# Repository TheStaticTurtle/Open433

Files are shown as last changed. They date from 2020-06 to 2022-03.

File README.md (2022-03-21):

# Open433

This project is an opensource usb 433Mhz rf transmitter / receiver based on an atmega328p the board uses a serial communication with a "packet" based systems (simples structs that are sent over the serial port).
The project has a basic but working implementation of a custom component for homeassistant  which is similar to the rpi_rf configuration)

See my blog articles on the implementation / creation of the project:

[https://blog.thestaticturtle.fr/open433-lets-turn-light-on-with-the-computer](https://blog.thestaticturtle.fr/open433-lets-turn-light-on-with-the-computer)

[https://blog.thestaticturtle.fr/creating-a-custom-component-for-homeassistant](https://blog.thestaticturtle.fr/creating-a-custom-component-for-homeassistant)

# Building the project

If you just got your own barebone pcbs you just need to flash the arduino bootloader to do that you can use any iscp programmer (or even "arduino as isp") for the bootloader I use the arduino uno bootloader the hardware is using an atmega328p running at 16MHz at 5V.
After that you just have to compile compile and upload the scketch in the arduino folder

# Using the project

## Using the library

If you don't use homeassistant you can see an example in the software folder.

## From homeassistant
If you want to use the board with homeassistant you need to create a `custom_components` folder in the homeassistant configuration directory (same one as the configuration.yaml) then you need to rename the `homeassistant_open433` to `open433` and put it in the `custom_components`.
Then after restarting the server you need to set the configure homeassistant to use the module:
```
open433:
  port: COM3
  speed: 9600 #(Optional default to 9600)
```
Then you can add switches like this:
```
switch:
  - platform: open433
    switches:
      KitchenLamp:
        code_on: 2523794944
        code_off: 2658012672
        protocol: 2 #(Optional default to 2)
        length: 32 #(Optional default to 32)
        signal_repetitions: 5 #(Optional default to 15)
        enable_receive: true #(Optional default to false) enable listening to incoming rf message of the switch codes
```
Or add binary sensors (with a possible timeout) like this:
```
binary_sensor:
  - platform: open433
    switches:
      inputA:
        code_on: 2389577216
        code_off: 2171473408
        protocol: 2 #(Optional default to 2)
        length: 32 #(Optional default to 32)
        on_timeout: 2 #(Optional 0 to turn off) Will turn off 2sec after receiving code_on, code_off will still be functional
```

An implementation of the light component has been done and can be used like this:
```
light:
  - platform: open433
    switches:
      BedSideLamp:
        levels:
          - brightness: 0
            code: 2658045484
          - brightness: 100
            code: 2523827756
        protocol: 2
        length: 32
        signal_repetitions: 5
        enable_receive: true
        force_levels: true
```
For this example, the entity KitchenLamp will send the code `2658045484` from brightness 0 to 99 and `2523827756` to 100 
The `force_levels` option allows the module to clamp homeassistant brightness slider to the specific value set in the config (ie. here sending the value 42 will go back to 0)
You can add multiple brightness stages with different codes, example:
```
- brightness: 0
  code: 2658045484
- brightness: 50
  code: 2926480940
- brightness: 100
  code: 2523827756
```
This will send the code `2658045484` from 0 to 49 , the code `2926480940` from 50 to 99 and the code `2523827756` at 100

You can also listen to events (open433_rx) to get received codes and send events to open433_tx with the following data to send an rf code:
```
code: 2658012672
protocol: 2
bitlength: 32
```

## Licences
- Software License: GPL v. 3
- Hardware License: CERN OHL v. 1.2
- Documentation License: CC BY-SA 4.0 International

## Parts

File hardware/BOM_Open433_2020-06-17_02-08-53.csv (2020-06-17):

ID | Name | Designator | Footprint | Quantity | Manufacturer Part | Manufacturer | Supplier | Supplier Part | LCSC Assembly
1 | HDR-M-2.54_2x2 | EXT | HDR-M-2.54_2X2 | 1 |  |  | LCSC | C66690
2 | 100nF | C4 | C1206 | 1 | FM31X104K251EEG | Prosperity Dielectrics | LCSC | C365814
3 | Antenna | U4,U6 | PCBANTENNA | 2 | ANT
4 | U217-04XN-XXR84 | USB1 | USB-A-SMD_U217-041N-4BV81 | 1 | U217-04XN-XXR84 | XKB Enterprise | LCSC | C319178
5 | 100nF | C3 | C1206 | 1 | GRM31C5C1H104JA01L | MuRata | LCSC | C97946
6 | DL-RXC2016BH-433M | U2 | WIRELM-TH_DL-RXC2016BH-433M | 1 | DL-RXC2016BH-433M | DreamLNK | LCSC | C381154
7 | 10K | R1,R4 | R1206 | 2 | CR-06JL7---10K | Viking Tech | LCSC | C280032
8 | 19-217/GHC-YR1S2/3T | LED2 | LED0603-R-RD | 1 | 19-217/GHC-YR1S2/3T | EVERLIGHT | LCSC | C72043 | Yes
9 | H34C-433MHZ | U1 | WIRELM-TH_H34C-433MHZ | 1 | H34C-433MHZ | Shenzhen LCHSTAR Elec | LCSC | C131030
10 | 19-223/Y2R6C-A01/2T | LED1 | LED-ARRAY-SMD_4P-L1.6-W1.5-TR-RD | 1 | 19-223/Y2R6C-A01/2T | Everlight Elec | LCSC | C282134
11 | TS665CJ | RST | SW-TH_4P-L6.0-W6.0-P4.50-LS6.5 | 1 | TS665CJ | SHOU HAN | LCSC | C393938
12 | Header-Female-2.54_2x3 | ISCP | HDR-3X2/2.54 | 1 | DS1023-2*3SF11 | CONNFLY | LCSC | C92272
13 | CH340G | U3 | SOIC-16_L9.9-W3.9-P1.27-LS6.0-BL | 1 | CH340G | WCH | LCSC | C14267 | Yes
14 | 12MHz | X1 | HC-49S_L11.4-W4.8 | 1 | C12000J517 | ZheJiang East Crystal Elec | LCSC | C279578
15 | 16MHz | X2 | HC-49S_L11.4-W4.8 | 1 | 49MD-16.000-20-20-20/A | Suzhou Liming Elec | LCSC | C240963
16 | 2.2K | R5,R6 | R0603 | 2 | QR0603F2K2P05 | Ever Ohms Tech | LCSC | C176136
17 | ATMEGA328P-AU | U5 | TQFP-32_L7.0-W7.0-P0.80-LS9.0-BL | 1 | ATMEGA328P-AU | MICROCHIP | LCSC | C14877 | Yes
18 | 22pF | C2,C1,C5,C6 | C1206 | 4 | 1206CG220J500NT | FH | LCSC | C1896

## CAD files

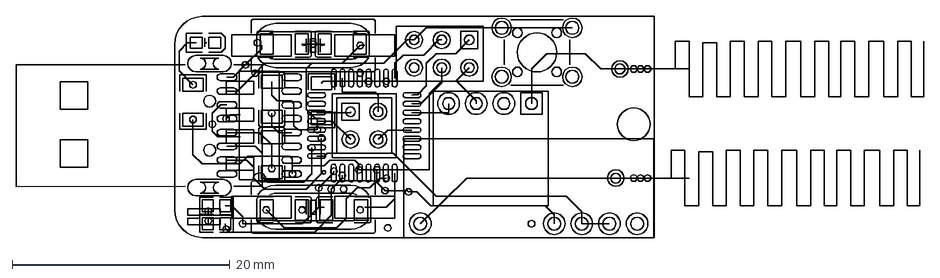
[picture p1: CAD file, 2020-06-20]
hardware/PCB_V2_2020-06-20_13-22-12.dxf
83.4 x 20.3 mm

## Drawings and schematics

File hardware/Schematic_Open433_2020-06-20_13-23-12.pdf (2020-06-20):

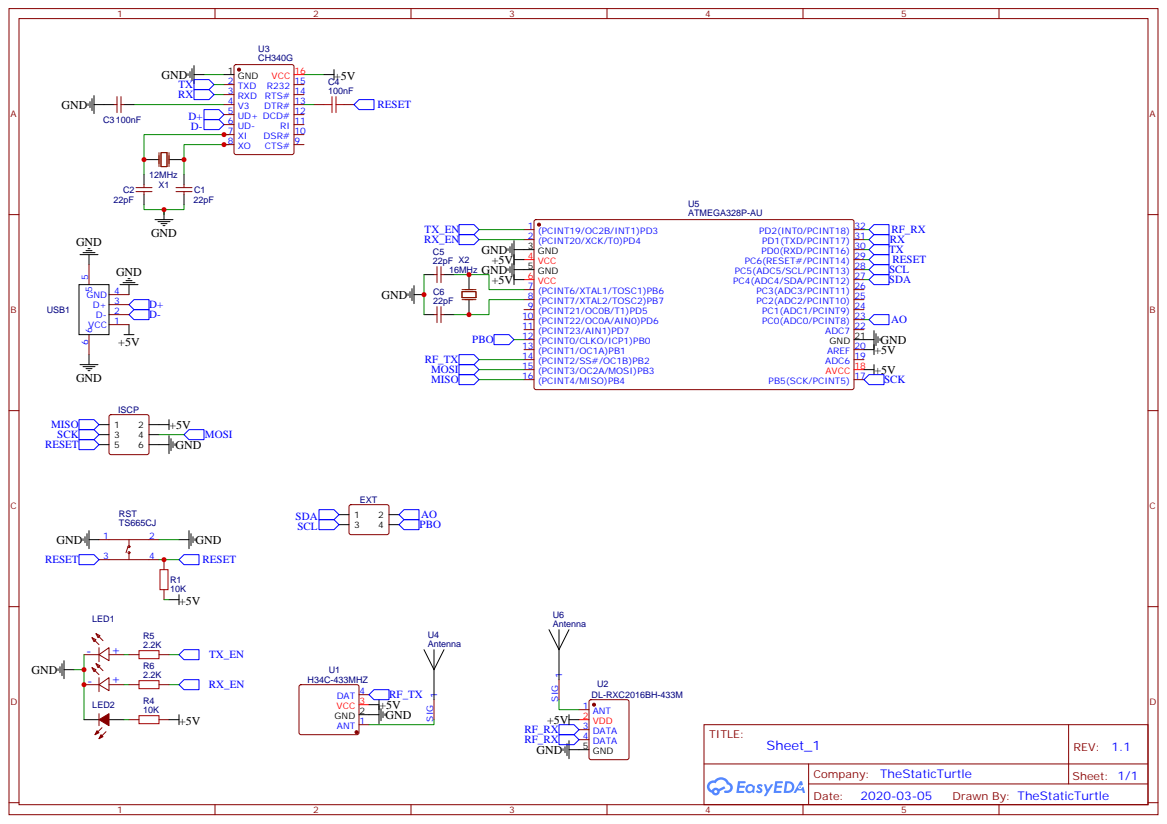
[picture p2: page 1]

DSR# 10 RI 11 DCD# 12 DTR# 13 RTS# 14 R232 15 VCC 16

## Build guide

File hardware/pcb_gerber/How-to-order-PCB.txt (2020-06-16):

How to Order PCB

Please refer to:
https://docs.easyeda.com/en/PCB/Order-PCB

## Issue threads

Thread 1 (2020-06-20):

HW source

pilotak, 2020-06-20:
Hi,
first of all nice project, i wanted to do the same. Would you be willing to share a source of PCB? only gerber appears to be uploaded. I can also see a schematic but in JSON format - what was the program you created it in? It would be nice to share a PDF schematic

TheStaticTurtle, 2020-06-20:
Just uploaded it now, I use EasyEDA as an editor this is where the json format came from. I also exported pdf / dxf / altium files

pilotak, 2020-06-20:
Thanks a lot.

@TheStaticTurtle You wrote on the blog that you tried a RF switch. Which one did you use? because i need to use only one SMA antenna

TheStaticTurtle, 2020-06-20:
I was using an HMC544AE but if I had to guess I think it would be more my shitty soldering / wiring that made it non-functional

pilotak, 2020-06-20:
OK, i think was thinking about following which are basically the same as Analog
- AS213-92LF
- CG2179M2-C4
- MASWSS0115TR-3000

Yes they have a tiny footprint but have at least pins as oppose to pads at the bottom totally unusable for home soldering

TheStaticTurtle, 2020-06-20:
Just some information the AS213-92LF has a 1.8 control voltage the other ones are fine with 5v but don't be like and forget the caps at the input / output

pilotak, 2020-06-20:
Datasheet says that it can be 1.8-5V. Thanks for the caps tip.

One more question did you use one output pin on arduino to control the switch (A+B tied together) or two separate pins

TheStaticTurtle, 2020-06-20:
Well you need two pins since one will control input A and the other B if you tie them together it will just not work (that's probably what happened to me)

Closed 2020-06-20.

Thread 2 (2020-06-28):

Frequency?

atrent, 2020-06-28:
Is it a 433.92 MHz standard?
If so would it be possible to support the 433.42 MHz standard? (e.g. Somfy)
Thanks

TheStaticTurtle, 2020-06-28:
All the frequencies / protocol working for the rc-switch library is compatible with this software (e.g. 315/433MHz), the receivers are usually wide enough to cover both the frequency you mentioned, if it isn't the case you can simply use ones that are compatible or change the quartz.

However, you still need the protocol. From what I can remember, somfy uses rolling codes which makes it much harder / impossible to control the device without the rolling algorithm.
However, I've just seen that the Somfy RTS or Simu HZ remote protocol have been reverse engineered so it might be possible. But I don't have the time right now

With a bit (lot) of work it would be possible to implement a multi-remote system with the correct rolling code for each one, here's documentation:
https://github.com/Nickduino/Somfy_Remote
https://pushstack.wordpress.com/somfy-rts-protocol/

Closed 2020-06-28.

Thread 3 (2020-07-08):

Universal code copying

createcandle, 2020-07-08:
I saw your project on Hackaday, nice job!

Last year I developed Arduino code that can clone and/or detect any 433mhz signal. By using compression it can even store up to 20 of these signals in eeprom.

By not relying on RCSwitch it can basically support any 433mhz power socket, and can detect and recognise the signals from any 433mhz window sensors, doorbells, and so forth. Might be interesting for your use case?

More here:
https://www.candlesmarthome.com/signal-hub

And the code can be found here:
https://github.com/createcandle/Devices/blob/master/Signal-hub/Signal-hub.ino

TheStaticTurtle, 2020-10-07:
Would be interesting but in order to not lose the home assistant component it would demand a big re-implementation to transfer the code each time instead of storing in the device.
Moreover, rc-switch already supports a great variety of outlets/lights even doorbells IIRC.
Your project looks really great but I don't have the time right now to re-implement +2000 lines of code into it right now (especially figuring out which part I need to keep and which I can throw away)
Not saying a "raw" mode won't happen in the future but not right now.

Thanks anyway.

Closed 2020-10-07.

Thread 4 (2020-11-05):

Support custom protocols

tobiasdiez, 2020-11-05:
First of all, I want to thank you for your work. I looked for days at different options, and nothing worked until I found your project. I had to make a few customization to the code, for which I will now open new issues/PRs.

rc-switch supports custom protocols that can be set as follows:
```
static const RCSwitch::Protocol customprotocol = { 296, {  17, 2 }, {  1, 2  }, { 2 , 1 }, false };
switch.setProtocol(customprotocol);
```
It would be nice if such a custom protocol could be specified in the home assistant config as well.

Moreover, I think the pulse length is implemented in the home assistant component, but not on the arduino side.

TheStaticTurtle, 2020-11-05:
Thanks for looking into this, I think you're right and I totally forgot to implement the pulse length on the Arduino side, for the custom protocol I think it's totally doable, it seems to be fixed size so not a big issue to add it to the `send_decimal_packet_t` struct receiving might me a bit more tricky, is there a way to listen to multiple protocol ?.

You're always welcome if you want to make PRs / issues

tobiasdiez, 2020-11-05:
The custom protocol is only used for transmitting I think, or at least this should be the most-common use case. Documentation can be found here: https://github.com/sui77/rc-switch/wiki/Add_New_Remote_Part_1

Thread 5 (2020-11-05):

Support light home assistant component

tobiasdiez, 2020-11-05:
It would be nice to have support for `light` components in home assistant. I'll open a PR for this, but wanted to ask you if you already have coded something in that direction.

Moreover, I wanted to ask what the config should look like. I guess most 433Mhz devices don't support continuous brightness changes. Thus I would propose something like the following
```
brightness:
   step:
       value: 10
       code:  Decimal code to set brightness to 10%
   step:
       value: 40
       code: ...
```
and for the devices that only have a lighter/darker controls:
```
brightness:
   lighter-code: Decimal code
   darker-code: Decimal code
   step: 20 (how much percentage the lighter/darker code change the brightness, e.g 20 -> 40)
```

TheStaticTurtle, 2020-11-05:
The first option seems easily doable, however the second one might be more tricky since the is no way of asking the lamp where it is and verifying that there isn't an offset (like ha thinking that it's at 100% and the lamp only 80%).

I don't really have anything to test that tho but I might be able to use an Arduino and make a test lamp with it.

TheStaticTurtle, 2020-11-09:
Commits 1aeb4f6dfe194787937b43c0144912148f304307 and 46b3360478c53d7c32a95df1d2a57e8f03a750d6 are the implementation of the light component.
They work on my side but do you have anything to test it with so that I can validate that it works everywhere ?

tobiasdiez, 2020-11-09:
Thanks a lot! Will test it in the coming days.

tobiasdiez, 2020-11-16:
It worked like a charm! Thanks!

Some minor improvements are in #8, but otherwise I consider this issue as fixed.

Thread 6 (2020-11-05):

Consider using ArduinoJSON as serial protocol

tobiasdiez, 2020-11-05:
Currently you use a custom serial protocol to communicate between the Arduino and the host. It might be more robust/extendable to use JSON as the format. This should also streamline the code somewhat.

[ArduinoJSON](https://arduinojson.org/) seems to be a great library for this. Of course, there is a bit of overhead involved when using JSON (see https://arduinojson.org/news/2019/11/19/arduinojson-vs-arduino_json/ for performance details).

TheStaticTurtle, 2020-11-05:
True I might look into it but you just thrown a lot of changes at me in no time 😃 so I will need some time to do all that especially since I don't have a lot of it

tobiasdiez, 2020-11-05:
Sure, take your time. There is no need for hurry!

TheStaticTurtle, 2020-11-09:
Opened a new branch for it (arduino_json_migration), might be a couple of weeks until I finish it really busy right now

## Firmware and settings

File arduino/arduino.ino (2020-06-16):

#include <RCSwitch.h>

#define BOARD_V01
#include "packets.h"
#include "board_definition.h"

#define BUFFER_SIZE 512

RCSwitch mySwitch = RCSwitch();
received_signal_packet_t packet_received_signal = {"receive_signal",0,0,0,0,0};
ack_packet_t ack_packet = {"ack",0,"hello world"};

uint8_t serial_buffer[BUFFER_SIZE];
uint8_t data_buffer[BUFFER_SIZE];
int bufferCounter = 0;
int dataBufferCounter = 0;
unsigned long last_message = 0;

void setup() {
  Serial.begin(9600);
  mySwitch.enableReceive(digitalPinToInterrupt(PIN_MODULE_RX));  // Receiver on interrupt 0 => that is pin #2
  mySwitch.enableTransmit(PIN_MODULE_TX);
  mySwitch.setRepeatTransmit(3);

  pinMode(PIN_LED_TX,OUTPUT);
  pinMode(PIN_LED_RX,OUTPUT);
  pinMode(PIN_LED_RX,HIGH);
  Serial.println("HELLO");
}

void sendAck() {
    ack_packet.t = millis();
    Serial.println("START"); //Send start marker
    uint8_t payload[sizeof(ack_packet)]; //Create temporary buffer to store the struct
    memcpy(payload,&ack_packet,sizeof(ack_packet)); //copy the struct to the tmp buffer
    for(int i=0;i < sizeof(payload);i++)  Serial.write(payload[i]); //Write the tmp buffer to serial port
    Serial.println("END"); //Send end marker
}

void loop() {
  digitalWrite(PIN_LED_RX,HIGH);
  if (mySwitch.available()) {
    //Assign values to send struct
    packet_received_signal.t        = millis();
    packet_received_signal.decimal  = mySwitch.getReceivedValue();
    packet_received_signal.length   = mySwitch.getReceivedBitlength();
    packet_received_signal.delay    = mySwitch.getReceivedDelay();
    packet_received_signal.protocol = mySwitch.getReceivedProtocol();
    
    Serial.println("START"); //Send start marker
    uint8_t payload[sizeof(packet_received_signal)]; //Create temporary buffer to store the struct
    memcpy(payload,&packet_received_signal,sizeof(packet_received_signal)); //copy the struct to the tmp buffer
    for(int i=0;i < sizeof(payload);i++)  Serial.write(payload[i]); //Write the tmp buffer to serial port
    Serial.println("END"); //Send end marker
    
    mySwitch.resetAvailable();
  }
  
  if(Serial.available()){
    last_message = millis();
    serial_buffer[bufferCounter] = Serial.read();
    
    char* search_start_pointer;
    search_start_pointer = strstr(serial_buffer, "START\r\n"); //Search for the "START\r\n" string in the serial receive buffer
    if (search_start_pointer != NULL) {
      data_buffer[dataBufferCounter] = serial_buffer[bufferCounter]; //Start copying incoming data to the data buffer but offseted so that it can be cast as a struc later
      if(data_buffer[dataBufferCounter-2] == 'E' && data_buffer[dataBufferCounter-1] == 'N' && data_buffer[dataBufferCounter] == 'D') { //Last 3 chars were END -> end of data
        char type[17];  //Create a tmp buffer to store the type of packet received
        memcpy (&type, &data_buffer, 17); //Copy only the first 17bytes to the tmp buffer (See ptype in each struct in packet.h)

        if(strstr(type,"send_decimal")!=NULL) { //SendDecimal packet found
          send_decimal_packet_t *test = (send_decimal_packet_t*) data_buffer; //Cast the data buffer to the struct representing the packet

          digitalWrite(PIN_LED_RX,LOW); //Led blinking
          digitalWrite(PIN_LED_TX,HIGH); 
          mySwitch.setProtocol(test->protocol); //Set the correct protocol according to the received packet
          mySwitch.send(test->decimal, test->length); //Send the value over the air
          digitalWrite(PIN_LED_TX,LOW); //Led blinking
  
          memset(data_buffer  , '\0', sizeof(char)*BUFFER_SIZE ); //Reset both buffers
          memset(serial_buffer, '\0', sizeof(char)*BUFFER_SIZE );
          sendAck();
        }
        if(strstr(type,"rcswitch_conf")!=NULL) { //SendDecimal packet found
          rcswitch_config_t *test = (rcswitch_config_t*) data_buffer; //Cast the data buffer to the struct representing the packet

          mySwitch.setRepeatTransmit(test->repeat);
          #if not defined( RCSwitchDisableReceiving )
          mySwitch.setReceiveTolerance(test->receiveTolerance);
          #endif
          
          memset(data_buffer  , '\0', sizeof(char)*BUFFER_SIZE ); //Reset both buffers
          memset(serial_buffer, '\0', sizeof(char)*BUFFER_SIZE );
          sendAck();
        }
        
        dataBufferCounter = -1; //Reset both buffers counters (-1 needed because of the ++ at the end of the loop)
        bufferCounter = -1;
      }
      dataBufferCounter++;
    }
    bufferCounter++;


    //Security measure. Ensure that the buffer will not overflow if the message. It also reset the buffers if the last message eceived was more than 30sec ago
    if((bufferCounter >= BUFFER_SIZE && dataBufferCounter >= BUFFER_SIZE) || last_message+30000 < millis()) {
      memset(data_buffer  , '\0', sizeof(char)*BUFFER_SIZE );
      memset(serial_buffer, '\0', sizeof(char)*BUFFER_SIZE );
      dataBufferCounter = 0;
      bufferCounter = 0;
    }
  }
}

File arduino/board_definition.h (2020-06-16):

#ifdef BOARD_V01

#define PIN_MODULE_RX 2
#define PIN_MODULE_TX 10
#define PIN_LED_TX 3
#define PIN_LED_RX 4

#endif

#ifdef BOARD_V00

#define PIN_MODULE_RX 2
#define PIN_MODULE_TX 10
#define PIN_LED_TX 9
#define PIN_LED_RX 8

#endif

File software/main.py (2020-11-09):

# import open433
import logging
import time

logging.basicConfig(level=logging.INFO, format='[%(asctime)s] [%(levelname)8s] %(name)10s - %(message)s')

import rcswitch

mySwitch = rcswitch.RCSwitch("COM3")
time.sleep(2)

for packet in mySwitch.listen():
 	print(packet)

packet_on  = rcswitch.packets.SendDecimal(value=2523794944, length=32, protocol=2, delay=700)
packet_off = rcswitch.packets.SendDecimal(value=2658012672, length=32, protocol=2, delay=700)

mySwitch.setRepeatTransmit(5)
mySwitch.libWaitForAck(True, timeout=5)

t=0.1
while True:
	print(mySwitch.send(packet_on))
	#mySwitch.receive_packet(timeout=0.1) #Would be great to receive an ACK
	time.sleep(t)

	print(mySwitch.send(packet_off))
	#mySwitch.receive_packet(timeout=0.1) #Would be great to receive an ACK
	time.sleep(t)

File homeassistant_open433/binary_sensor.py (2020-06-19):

"""Support for binary sensor using RPi GPIO."""
import logging
from threading import Timer

import voluptuous as vol

from homeassistant.components.binary_sensor import PLATFORM_SCHEMA, BinarySensorEntity
from homeassistant.const import CONF_NAME, CONF_SWITCHES, DEVICE_DEFAULT_NAME
import homeassistant.helpers.config_validation as cv
from . import DOMAIN, REQ_LOCK, rcswitch

_LOGGER = logging.getLogger(__name__)

CONF_CODE_OFF = "code_off"
CONF_CODE_ON = "code_on"
CONF_PROTOCOL = "protocol"
CONF_LENGTH = "length"
CONF_SIGNAL_REPETITIONS = "signal_repetitions"
CONF_ON_TIMEOUT = "on_timeout"

SWITCH_SCHEMA = vol.Schema(
	{
		vol.Required(CONF_CODE_OFF): vol.All(cv.ensure_list_csv, [cv.positive_int]),
		vol.Required(CONF_CODE_ON): vol.All(cv.ensure_list_csv, [cv.positive_int]),
		vol.Optional(CONF_LENGTH, default=32): cv.positive_int,
		vol.Optional(CONF_SIGNAL_REPETITIONS, default=15): cv.positive_int,
		vol.Optional(CONF_PROTOCOL, default=2): cv.positive_int,
		vol.Optional(CONF_PROTOCOL, default=2): cv.positive_int,
		vol.Optional(CONF_ON_TIMEOUT, default=0): cv.positive_int,
	}
)

PLATFORM_SCHEMA = PLATFORM_SCHEMA.extend(
	{
		vol.Required(CONF_SWITCHES): vol.Schema({cv.string: SWITCH_SCHEMA}),
	}
)


def setup_platform(hass, config, add_entities, discovery_info=None):
	rf = hass.data[DOMAIN]

	switches = config.get(CONF_SWITCHES)
	devices = []
	for dev_name, properties in switches.items():
		devices.append(
			Open433BinarySensor(
				properties.get(CONF_NAME, dev_name),
				rf,
				properties.get(CONF_PROTOCOL),
				properties.get(CONF_LENGTH),
				properties.get(CONF_CODE_ON),
				properties.get(CONF_CODE_OFF),
				properties.get(CONF_ON_TIMEOUT),
			)
		)

	add_entities(devices, True)


class Open433BinarySensor(BinarySensorEntity):
	def __init__(self, name, rf, protocol, length, code_on, code_off, on_timeout):
		self._name = name
		self._state = False
		self._rf = rf
		self._protocol = protocol
		self._length = length
		self._code_on = code_on
		self._code_off = code_off
		self._on_timeout = on_timeout
		self._available = True
		self._rf.addIncomingPacketListener(self._incoming)

		self._rf.addErrorListener(self._rcSwitchError)

	def _rcSwitchError(self, err):
		self._available = False
		self.schedule_update_ha_state()

	def _turn_off(self):
		self._state = False
		self.schedule_update_ha_state()

	def _incoming(self, packet):
		if isinstance(packet, rcswitch.packets.ReceivedSignal):
			if packet.length == self._length and packet.protocol == self._protocol:
				if packet.decimal in self._code_on:
					self._state = True
					self.schedule_update_ha_state()
					if self._on_timeout != 0:
						Timer(self._on_timeout, self._turn_off).start()

				if packet.decimal in self._code_off:
					self._state = False
					self.schedule_update_ha_state()

	@property
	def available(self):
		return self._available

	@property
	def should_poll(self):
		return False

	@property
	def name(self):
		return self._name

	@property
	def is_on(self):
		return self._state

	def update(self):
		pass

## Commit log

2020-06-16 Added arduino board code
2020-06-16 Added hardware files (gerber + schematic)
    [Gerber_BoardOutline.GKO, Gerber_BottomLayer.GBL, Gerber_BottomPasteMaskLayer.GBP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]
2020-06-17 Added bom list for the pcb
    [BOM_Open433_2020-06-17_02-08-53.csv]
2020-06-17 Added the enable_receive option to the switch component
2020-06-18 Fixed timeout issue while reading ack
    [rcswitch.py, switch.py]
2020-06-18 Fixed timeout issue during serial_sync
    [rcswitch.py]
2020-06-19 Added proper error handeling to set the correct statuses when an error
    [binary_sensor.py, rcswitch.py, switch.py]
2020-06-20 Added other formats for pcb / schematics
    [PCB_V2_2020-06-20_13-22-12.dxf, PCB_V2_2020-06-20_13-22-27.pcbdoc]
2020-11-09 Added a way to force the slider to the correct values
    [light.py]
2020-11-09 Removed debug prints
